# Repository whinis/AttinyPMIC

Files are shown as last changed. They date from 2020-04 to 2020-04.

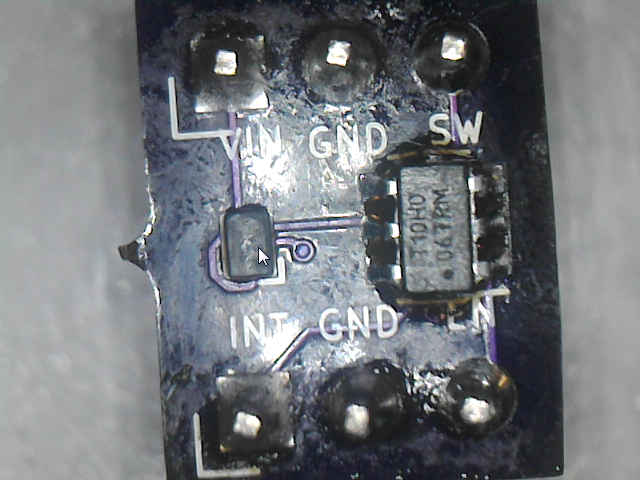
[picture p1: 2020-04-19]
Images/Breakout.png

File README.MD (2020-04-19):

### Project

I was working on a project where I wanted a soft On/Off button such that whenever you pressed a button the power turned on but whenever you held the button the power turned off, low power as it was a battery powered application, and could work even if the main microprocessor locked up or had another error. I was shocked to learn there was few parts for this application and the ones that did exists were expensive relative to everything else. I started looking into different ways of doing this and they all either involved a ton of board space and drew a fairly significant amount(1ma+) of power or cost upwards more than $1 per IC which in hobby price is outrageous.  So I tried another route.

This implementation takes an Attiny4,5,6 or 10 and implements an interrupt on one pin that should be connected to a standard push button. One pin is used as a general interrupt to inform the button has been pressed. Another pin is used as an output to either a transistor, ideal diode, or regulator, this pin is pulled high as an input once the button is pressed. Once the button is held down for ~ 5 seconds the output pin is pulled low as an output before becoming an input again. The attiny is asleep outside of these events. The reset pin is left unchanged so that you can easily reprogram

### Features
- Low cost ($0.27 per attiny)
- Low Power (<0.1µa)
- Allows Microprocessor to control output as well 
Since the output in is just an input with a pullup its easy to overpower with a true output or in testing. The software will monitor or external force forcing the pin low and disable its output as well.
- Small form factor (Sot23-6 or UDFN-8)
- Configurable
	With this being a micro rather than fixed silicon you can change which pins do which if your designs change without issue

### In this Repository
In the code directory is the main.c that contains the code. It was made in [https://github.com/wholder/ATTiny10IDE](https://github.com/wholder/ATTiny10IDE "https://github.com/wholder/ATTiny10IDE") which is a wonderful simple IDE for Attiny10 family of microprocessors. You can program to the Attiny using a standard arduino.

In the Hardware directory is some breakout board files in Kicad I used on my breadboards and can be used as example circuits. Both boards use a LDO on the board to control the output level of the attiny 10, if you are not using the interrupt you can likely connect directly to your battery. PMIC v2 uses a LDO that makes the entire circuit < 1µa which should be less than most batteries self-discharge rate.

Images contains images of the breakout board.

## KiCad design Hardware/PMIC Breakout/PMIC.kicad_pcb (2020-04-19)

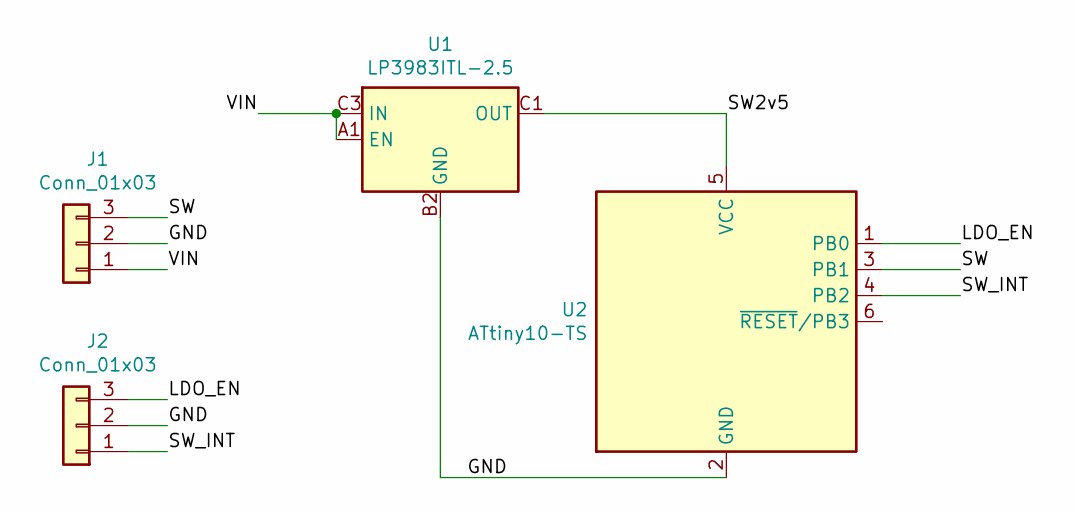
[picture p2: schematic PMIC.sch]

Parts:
J1, J2: Conn_01x03; PinHeader_1x03_P2.54mm_Vertical
U1: LP3983ITL-2.5; Texas_DSBGA-5_0.822x1.116mm_Layout2x1x2_P0.4mm
U2: ATtiny10-TS; SOT-23-6

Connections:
/GND: J1.2, J2.2, U1.B2 (GND), U2.2 (GND)
/LDO_EN: J2.3, U2.1 (PB0)
/SW: J1.3, U2.3 (PB1)
/SW2v5: U1.C1 (OUT), U2.5 (VCC)
/SW_INT: J2.1, U2.4 (PB2)
/VIN: J1.1, U1.A1 (EN), U1.C3 (IN)

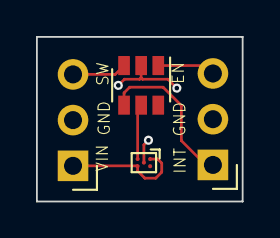
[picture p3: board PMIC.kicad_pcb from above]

Board: 2 copper layers, 11.4 x 9.1 mm, 4 parts (0 on the bottom side), 6 nets.

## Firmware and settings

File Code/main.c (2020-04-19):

#pragma chip attiny10
#pragma lfuse 0x62          // default value
#pragma hfuse 0xDF          // default value
#pragma efuse 0xFF          // default value


#define F_CPU 256000UL
#include <avr/io.h>
#include <avr/interrupt.h>
#include <avr/sleep.h>
#include <util/delay.h>

void goToSleep ();

uint8_t button = 0;

#define BUTTON PB1			// Pin used as button to trigger LDO_EN
#define INT_OUT PB2			// Pin used as interrupt to inform other things button was pressed
#define LDO_EN PB2			// Pin used to enable LDO
#define HOLD_TIME 300		// counter button is held for before disabling LDO_EN


int main () {
	CCP = 0xD8;			    // Unprotect CLKPSR reg
  	CLKPSR = 5;             // Set clock to 64khz
	OSCCAL=0x59;
	ADCSRA &= ~_BV(ADEN);	// Disable ADC, we never need it
	PCICR = 1;				// Enable Pin Change Interrupt
	PCMSK  |= _BV(PCINT1)   // Enables Pin Change on PCINT1
			| _BV(PCINT0);  // Enables Pin Change on PCINT0

	PUEB |=_BV(BUTTON);		//Set PB2 to have a pullup
	DDRB |=_BV(INT_OUT);		//Set PB1 to be an output
	uint16_t counter = 0;
	char debounce = 0;
  	while (true) {
		if(button == 1){
			if(debounce >0)
				debounce -= 1;		//disable denounce counter
			if(counter > HOLD_TIME){ // shuts off at roughly 6 seconds
				PUEB &= ~_BV(LDO_EN);  //Disable PB0(LDO_EN) pullup to turn off
    			PORTB &= ~_BV(LDO_EN);  //Set PB0(LDO_EN) as Low
    			DDRB |= (1 << LDO_EN);	//set PB0 as output temperorarily to force off
    			debounce = 0;
			}else{
				counter+=1; //prevent counter from overflowing
			}
		}else if(counter > 0){
			debounce +=1;
			if(debounce > 15){
				counter = 0;
				debounce = 0;
			}
		}
		if(counter == 0 && debounce == 0){ //go to sleep if the power switch has not recently been pressed
			DDRB &= ~_BV(PB0);	//set PB0 as input again
			goToSleep();		// we are setup, go to sleep
		}
		_delay_ms(10);
  	}
}

void goToSleep ()
{    
	set_sleep_mode(SLEEP_MODE_PWR_DOWN);
	sleep_enable();
	sei();					// turn on interrupts
	sleep_cpu();
	sleep_disable();
}

ISR(PCINT0_vect)
{
	cli();
	//button is pressed or not pressed.
	if((PINB &_BV(BUTTON))== 0){
		PUEB |=_BV(LDO_EN);	//Set PB0(EN) to have a pullup to fake it being an output
		PORTB |= _BV(INT_OUT);	//set Interrupt to MCU
		button = 1;
	}else{
		PORTB &= ~_BV(INT_OUT); //clear Interrupt to MCU
		button = 0;
	}

	//the MCU forced off the power
	if((PINB &_BV(LDO_EN))== 0){
		PUEB &= ~_BV(LDO_EN);  //Disable PB0(EN) pullup to turn off
	}
}
